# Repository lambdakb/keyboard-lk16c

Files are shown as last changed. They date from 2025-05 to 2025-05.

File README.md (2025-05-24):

# LK16C 4x4 Daisy-Chainable Keyboard PCB






## PCB

| PCB (Front) | PCB (Back) |
| :---: | :---: |
| [PCB Front][PCB Front PNG] | [PCB Back][PCB Back PNG] |

[PCB Front]: output/pcb/img/lk16c-pcb-top.svg
[PCB Front PNG]: output/pcb/img/lk16c-pcb-top.png
[PCB Back]: output/pcb/img/lk16c-pcb-bottom.svg
[PCB Back PNG]: output/pcb/img/lk16c-pcb-bottom.png

The PCB has been designed in [KiCad EDA 9.0](https://www.kicad.org/) using the [`kicad-lkbd`](https://github.com/lambdakb/kicad-lkbd) libraries and [`kbplacer`](https://github.com/adamws/kicad-kbplacer).

You can preview the project files using [KiCanvas](https://kicanvas.org/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) directly in your browser and download the latest fabrication files for JLCPCB from the [latest release](https://github.com/lambdakb/keyboard-lk16c/releases/latest/).

The exported schematic is also available under [`output/schematics`](output/schematics/).

### PCB Order

| Parameters | Value |
| --- | --- |
| Base Material | FR4 |
| Layers | 2 |
| Dimensions | 76.2 mm × 76.2 mm |
| PCB Thickness | 1.6 mm |
| PCB Color [^pcb-color] | Black |
| Silkscreen | White |
| Surface Finish [^surface-finish] | Lead Free HASL or ENIG |
| Copper Weight | 1 oz |
| Via Covering | Tented |
| Min Via Hole Size | 0.3 mm |
| Board Outline Tolerance | ± 0.2 mm |

[^pcb-color]: You can select any PCB color you want but some manufacturers such as JLCPCB may charge you more for uncommon combos (such as Blue PCB + ENIG Surface Finish).
[^surface-finish]: The "HASL (with lead)" option is extremely discouraged due to the risk of lead poisoning. We strongly recommend paying the premium for the "Lead Free HASL" option.

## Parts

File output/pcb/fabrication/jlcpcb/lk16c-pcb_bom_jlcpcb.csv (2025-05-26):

Comment | Designator | Footprint Type | Footprint | LCSC | JLC | QTY
1N4148 | D1,D2,D3,D4,D5,D6,D7,D8,D9,D10,D11,D12,D13,D15,D17,D19 | SMD | Diode_SMD_SOD-123_inSilk | C81598 | SOD-123 | 16
SW_Push | SW1,SW2,SW3,SW4,SW5,SW6,SW7,SW8,SW9,SW10,SW11,SW12,SW13,SW14,SW15,SW16,SW17,SW18,SW19 | SMD | SW_MX_Slim_HotSwap_THT_sqSilk | C41430893 | SMD,14.5x5.9mm | 19

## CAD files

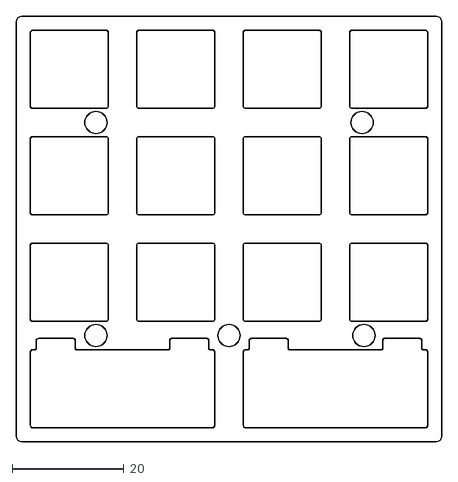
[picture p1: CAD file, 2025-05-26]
output/plate/dxf/lk16c-plate_2space.dxf
76.2 x 76.2

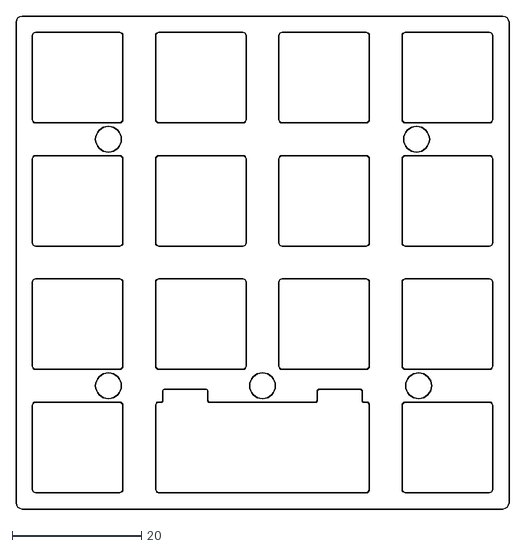
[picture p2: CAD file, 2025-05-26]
output/plate/dxf/lk16c-plate_regular.dxf
76.2 x 76.2

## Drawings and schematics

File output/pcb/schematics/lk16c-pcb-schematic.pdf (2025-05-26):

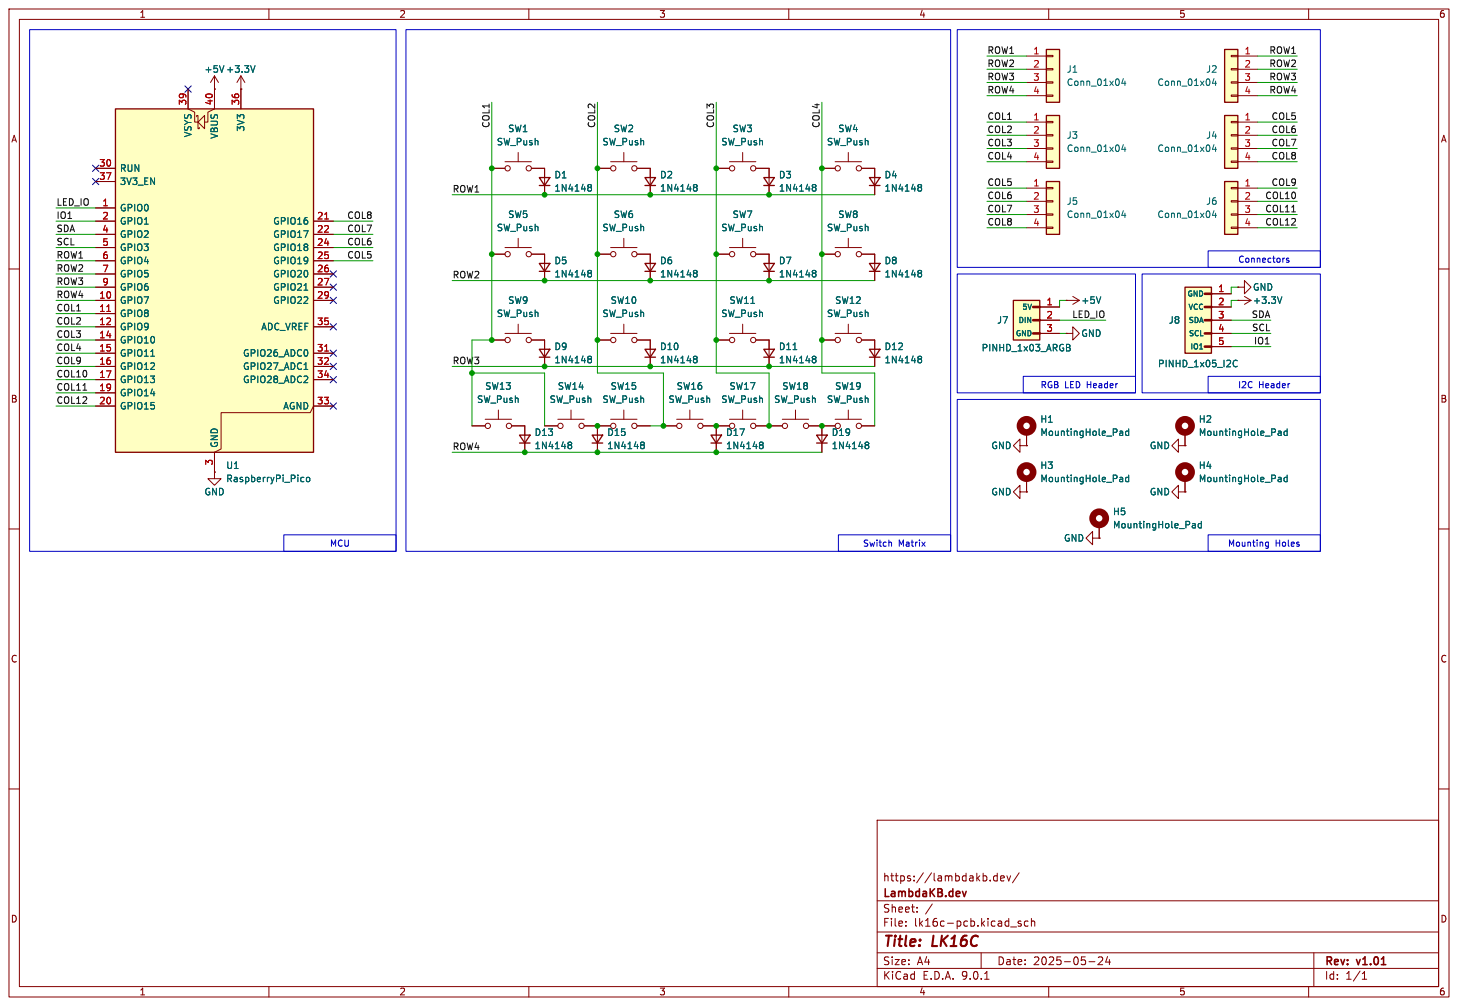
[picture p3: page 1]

I2C Header Connectors MCU GND

https://lambdakb.dev/
File: lk16c-pcb.kicad_sch Sheet: / LambdaKB.dev

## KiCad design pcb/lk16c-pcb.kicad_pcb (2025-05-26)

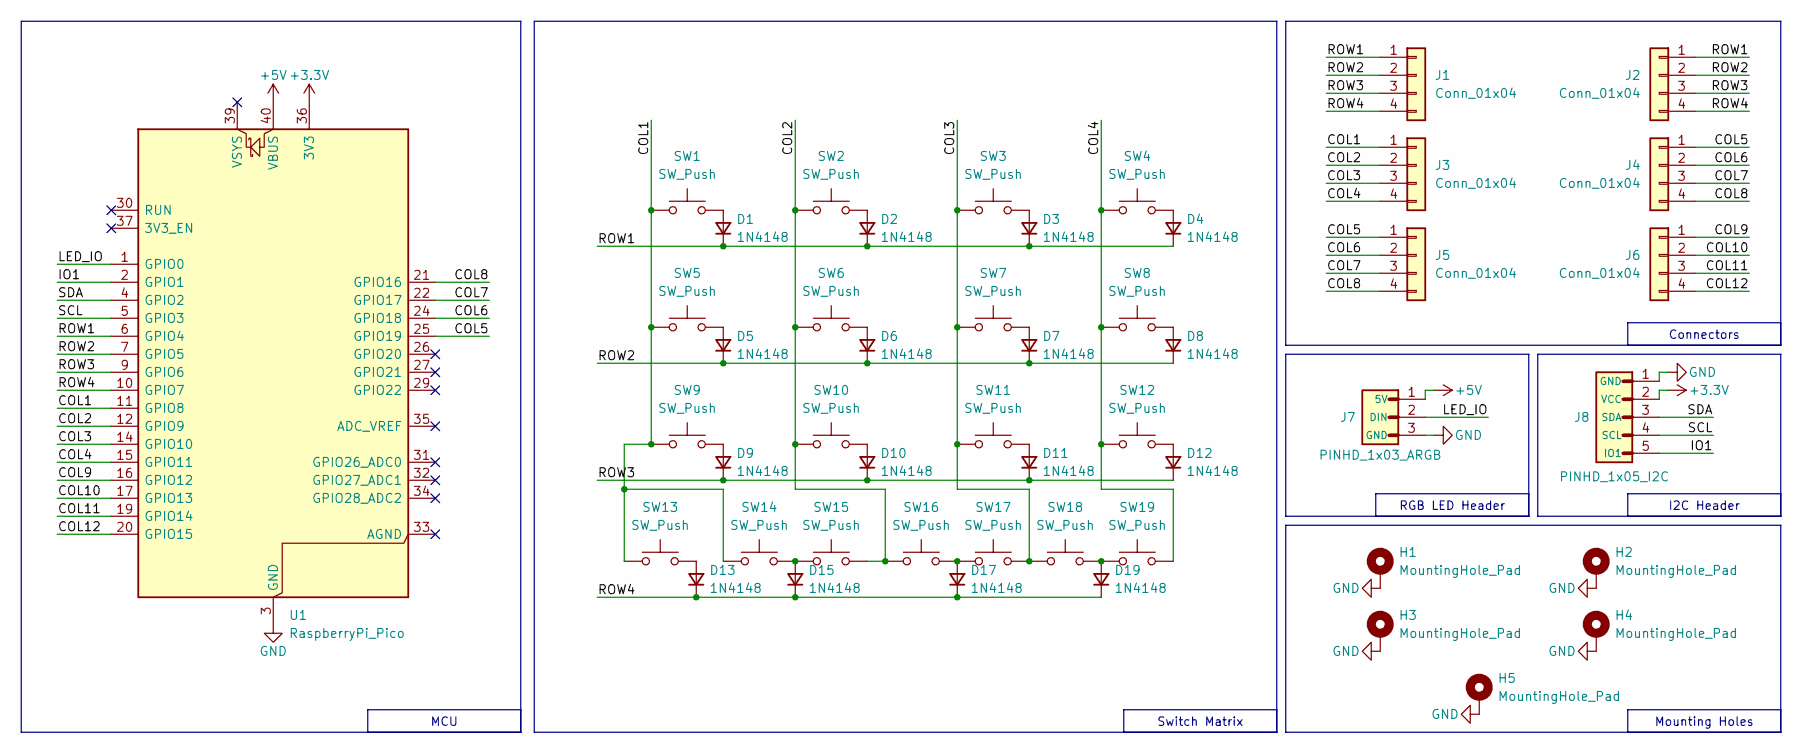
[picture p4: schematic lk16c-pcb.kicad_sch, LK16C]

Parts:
D1, D2, D3, D4, D5, D6, D7, D8, D9, D10, D11, D12, D13, D15, D17, D19: 1N4148; Diode_SMD_SOD-123_inSilk; LCSC C81598
H1, H2, H3, H4, H5: MountingHole_Pad; MountingHole_M2
J1, J3, J5: Conn_01x04; EdgeHeader_1x04_THT_P2.54mm_Right
J2, J4, J6: Conn_01x04; EdgeHeader_1x04_THT_P2.54mm_Left
J7: PINHD_1x03_ARGB; PinHeader_1x03_THT_P2.54mm_nSilk
J8: PINHD_1x05_I2C; PinHeader_1x05_THT_P2.54mm_nSilk
SW1, SW2, SW3, SW4, SW5, SW6, SW7, SW8, SW9, SW10, SW11, SW12, SW13, SW14, SW15, SW16, SW17, SW18, SW19: SW_Push; SW_MX_Slim_HotSwap_THT_sqSilk; JLC SMD,14.5x5.9mm
U1: RaspberryPi_Pico; MCU_RaspberryPi_Pico_THT

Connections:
+3.3V: J8.2 (VCC), U1.36 (3V3)
+5V: J7.1 (5V), U1.40 (VBUS)
/COL1: J3.1, SW1.2, SW5.2, SW9.2, SW13.2, SW14.2, U1.11 (GPIO8)
/COL2: J3.2, SW2.2, SW6.2, SW10.2, SW15.2, SW16.2, U1.12 (GPIO9)
/COL3: J3.3, SW3.2, SW7.2, SW11.2, SW17.2, SW18.2, U1.14 (GPIO10)
/COL4: J3.4, SW4.2, SW8.2, SW12.2, SW19.2, U1.15 (GPIO11)
/COL5: J4.1, J5.1, U1.25 (GPIO19)
/COL6: J4.2, J5.2, U1.24 (GPIO18)
/COL7: J4.3, J5.3, U1.22 (GPIO17)
/COL8: J4.4, J5.4, U1.21 (GPIO16)
/COL9: J6.1, U1.16 (GPIO12)
/COL10: J6.2, U1.17 (GPIO13)
/COL11: J6.3, U1.19 (GPIO14)
/COL12: J6.4, U1.20 (GPIO15)
/IO1: J8.5 (IO1), U1.2 (GPIO1)
/LED_IO: J7.2 (DIN), U1.1 (GPIO0)
/ROW1: D1.1 (K), D2.1 (K), D3.1 (K), D4.1 (K), J1.1, J2.1, U1.6 (GPIO4)
/ROW2: D5.1 (K), D6.1 (K), D7.1 (K), D8.1 (K), J1.2, J2.2, U1.7 (GPIO5)
/ROW3: D9.1 (K), D10.1 (K), D11.1 (K), D12.1 (K), J1.3, J2.3, U1.9 (GPIO6)
/ROW4: D13.1 (K), D15.1 (K), D17.1 (K), D19.1 (K), J1.4, J2.4, U1.10 (GPIO7)
/SCL: J8.4 (SCL), U1.5 (GPIO3)
/SDA: J8.3 (SDA), U1.4 (GPIO2)
GND: H1.1, H2.1, H3.1, H4.1, H5.1, J7.3 (GND), J8.1 (GND), U1.3 (GND), U1.8 (GND), U1.13 (GND), U1.18 (GND), U1.23 (GND), U1.28 (GND), U1.38 (GND)
unnamed: D1.2 (A), SW1.1
unnamed: D2.2 (A), SW2.1
unnamed: D3.2 (A), SW3.1
unnamed: D4.2 (A), SW4.1
unnamed: D5.2 (A), SW5.1
unnamed: D6.2 (A), SW6.1
unnamed: D7.2 (A), SW7.1
unnamed: D8.2 (A), SW8.1
unnamed: D9.2 (A), SW9.1
unnamed: D10.2 (A), SW10.1
unnamed: D11.2 (A), SW11.1
unnamed: D12.2 (A), SW12.1
unnamed: D13.2 (A), SW13.1
unnamed: D15.2 (A), SW14.1, SW15.1
unnamed: D17.2 (A), SW16.1, SW17.1
unnamed: D19.2 (A), SW18.1, SW19.1

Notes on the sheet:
Connectors
RGB LED Header
Mounting Holes
I2C Header
MCU
Switch Matrix

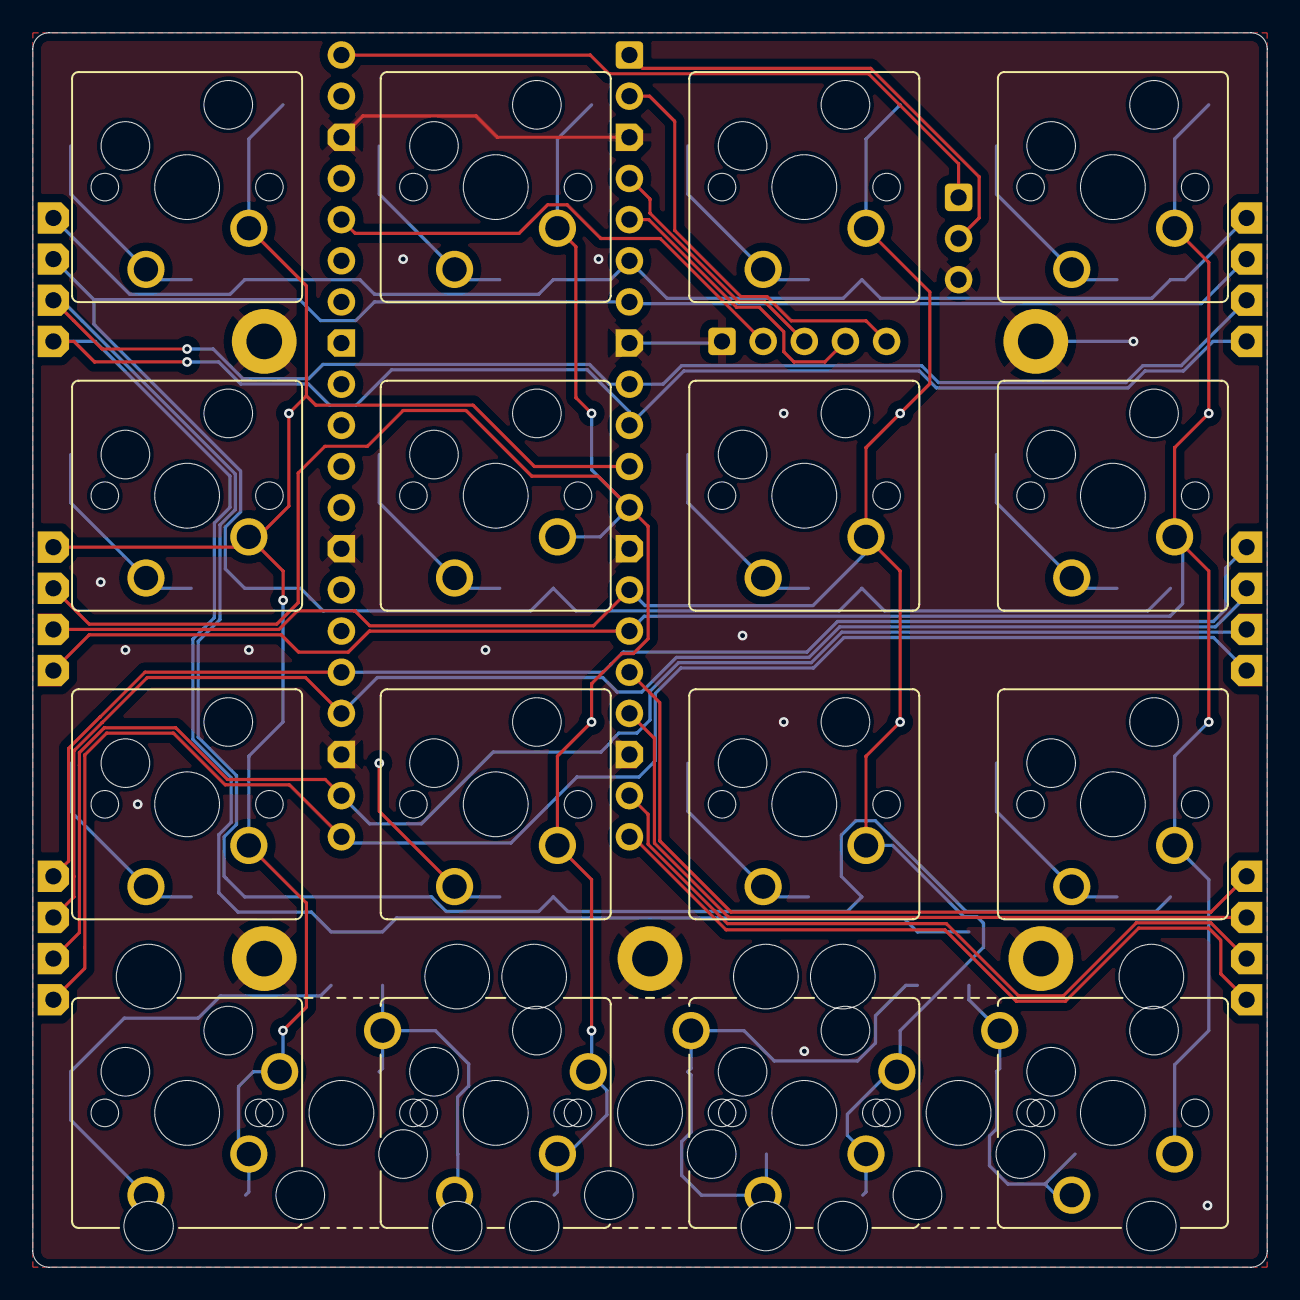
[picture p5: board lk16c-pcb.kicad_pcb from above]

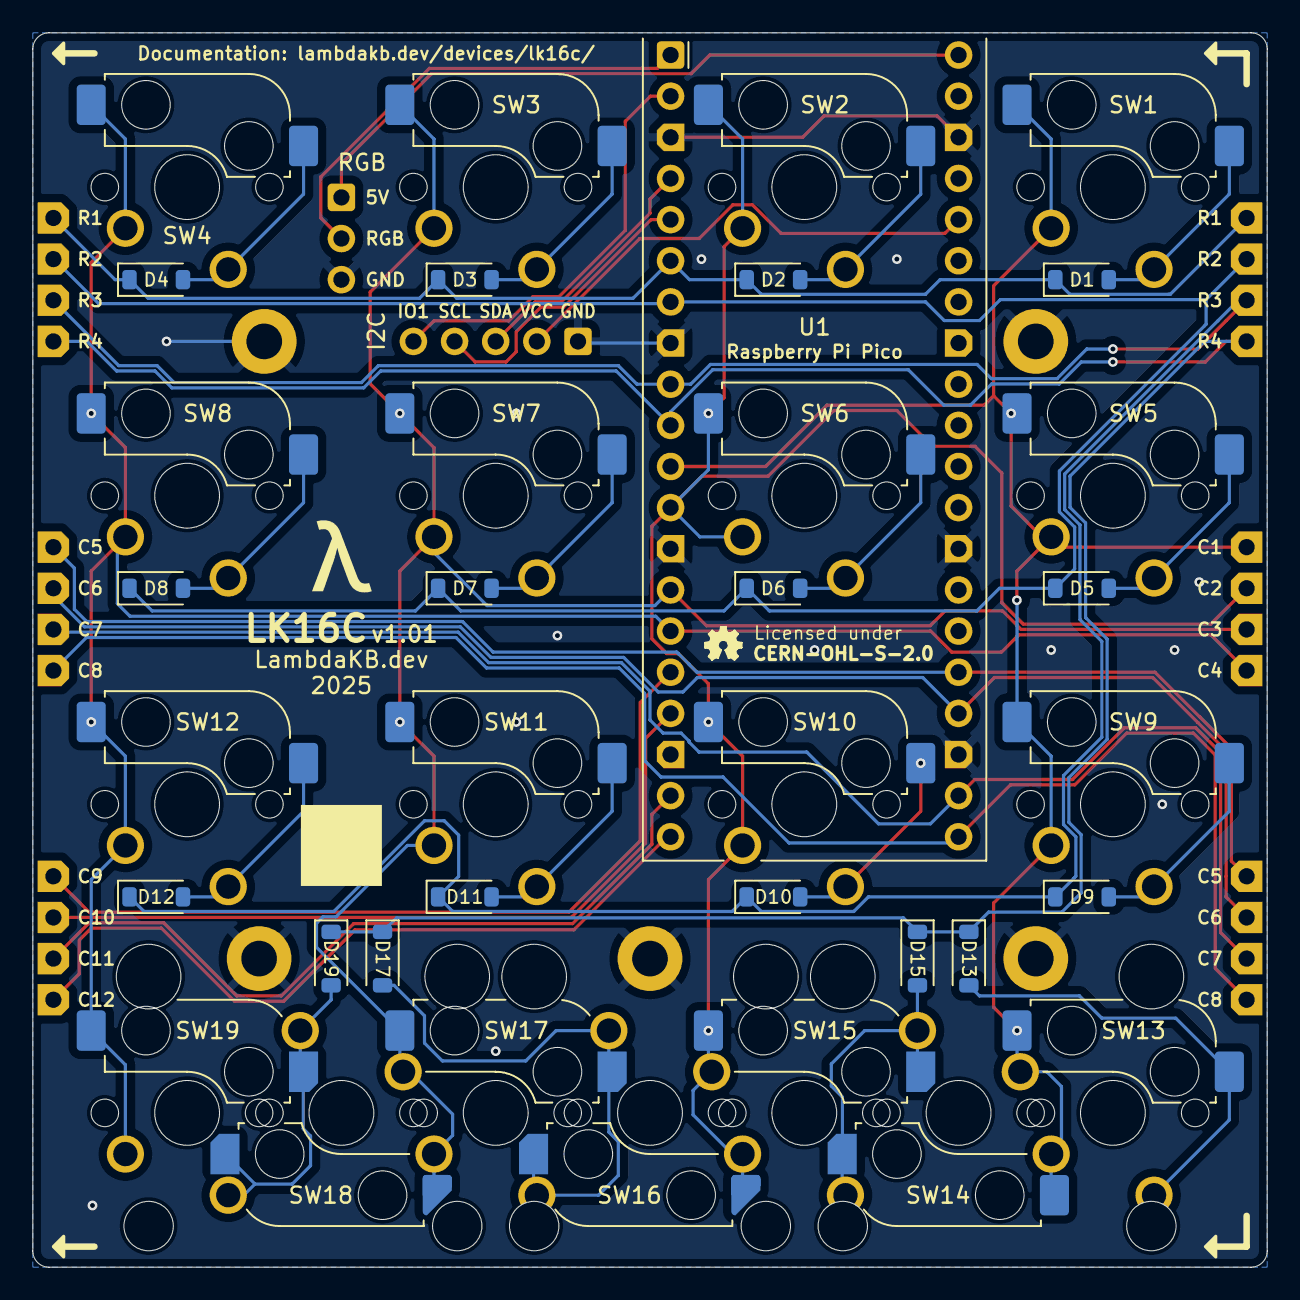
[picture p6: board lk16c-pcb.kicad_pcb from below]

Board: 2 copper layers, 76.2 x 76.2 mm, 53 parts (45 on the bottom side), 39 nets.

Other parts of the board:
S14, S16, S18: MX_stab; Stabilizer_MX_2U
TXT1: JLCPCB_2DBarcode_5x5mm

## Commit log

2025-05-13 Initial prototype
    [lk16c-pcb-3D.step, lk16c-pcb.kicad_pcb, lk16c-pcb.kicad_sch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]
2025-05-14 Add plate and cleanup schematic
    [lk16c-pcb-3D.step, lk16c-pcb.kicad_pcb, lk16c-pcb.kicad_sch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]
2025-05-14 Update board to board connector (#1)
    [lk16c-pcb-3D.step, lk16c-pcb.kicad_pcb, lk16c-pcb.kicad_sch]
2025-05-14 Update PCB from Schematic
    [lk16c-pcb.kicad_pcb]
2025-05-24 Add more space between board to board connectors (#2)
    * Update LKBD and move edge connectors to leave space for an LED stirp
    * Format README.md
    * Update pcbdraw color
    [lk16c-pcb-3D.step, lk16c-pcb.kicad_pcb, lk16c-pcb.kicad_sch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]
2025-05-26 Add ability to use 2× 2U Spacebars as the bottom row (#3)
    * Add ability to use 2× 2U Spacebars as the bottom row
    * Move Fab DataMatrix footprint
    * Add plate variant for 2space
    * Fix mounting hole paste
    [lk16c-pcb.kicad_pcb, lk16c-pcb.kicad_sch, lk16c-pcb_bom_jlcpcb.csv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]
2025-05-26 Bump version to v1.01
    [lk16c-pcb.kicad_pcb]

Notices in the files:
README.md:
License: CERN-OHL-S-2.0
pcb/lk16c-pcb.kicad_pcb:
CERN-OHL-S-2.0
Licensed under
